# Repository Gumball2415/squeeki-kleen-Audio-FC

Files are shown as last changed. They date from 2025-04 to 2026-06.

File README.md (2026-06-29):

# squeeki-kleen! Audio FC

an open-source hardware external preamp modboard for the NES and FamiCom

## About

A few months ago, I discovered the main source of noisy interference for the audio in the FamiCom, which is the hex inverter chip. The other signals passing through the hex inverter chip is the interference heard in the audio.

Therefore, to reduce the interference as much as possible, the APU pins and preamp circuit must be completely isolated from the hex inverter chip. This is where this modboard comes in.

Note that this KiCad project is optimized for JLCPCB manufacturing, so you may have to modify how the gerber files are generated, remove the part number silkscreen on the back, etc.

<div align="center">
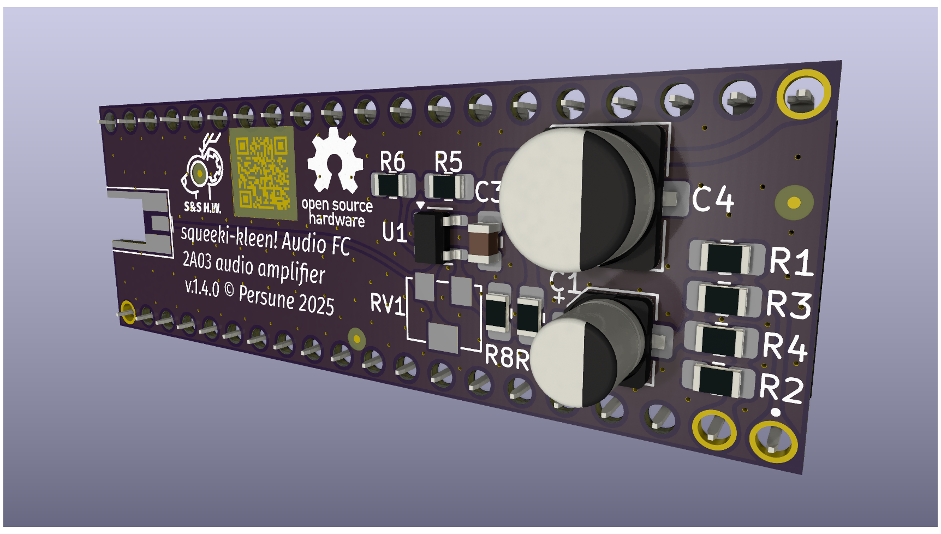
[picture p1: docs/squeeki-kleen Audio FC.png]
	
</div>

## Installation

This demonstration uses the RF FamiCom motherboard, revision CPU-07. However, these requirements can be easily adapted to different consoles and motherboard revisions, such as the NES.

This demonstration also uses an earlier revision board, so the look may differ, but the instructions should remain the same.

Here is the full motherboard overview of what modifications need to be done:

<div align="center">

</div>

### Instructions

1. Isolate Pin 1 and 2 of the 2A03 by cutting their traces as shown:

<div align="center">
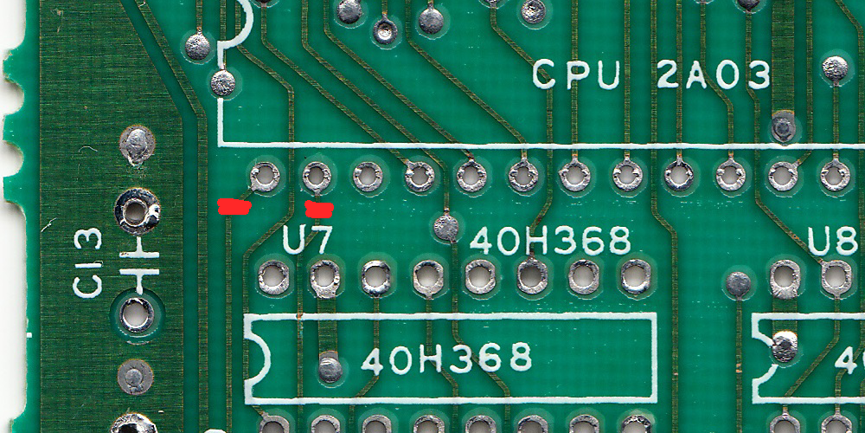
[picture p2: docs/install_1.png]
	
</div>

2. Short the input of the stock preamp circuit to ground (solder bridge violet, pins 14 and 15 of U7)

<div align="center">
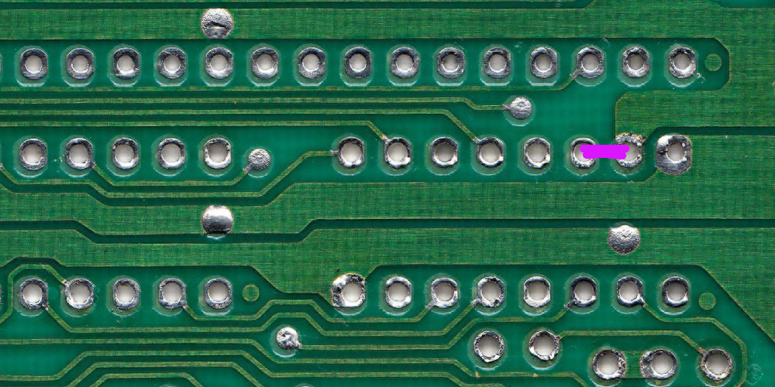
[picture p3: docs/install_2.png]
	
</div>

3. Isolate the output of the stock preamp circuit and the old audio path (cut blue)
	- Cut the trace after the `SOU` test pad
	- Cut the trace of R7 before it goes to pin 13 of U7
	- Isolate the via near C11, which leads to pin 45 of the cartridge slot. This prevents the leftover trace leaving the `SOU` test pad acting as an antenna to unwanted interference near the bus traces.

<div align="center">
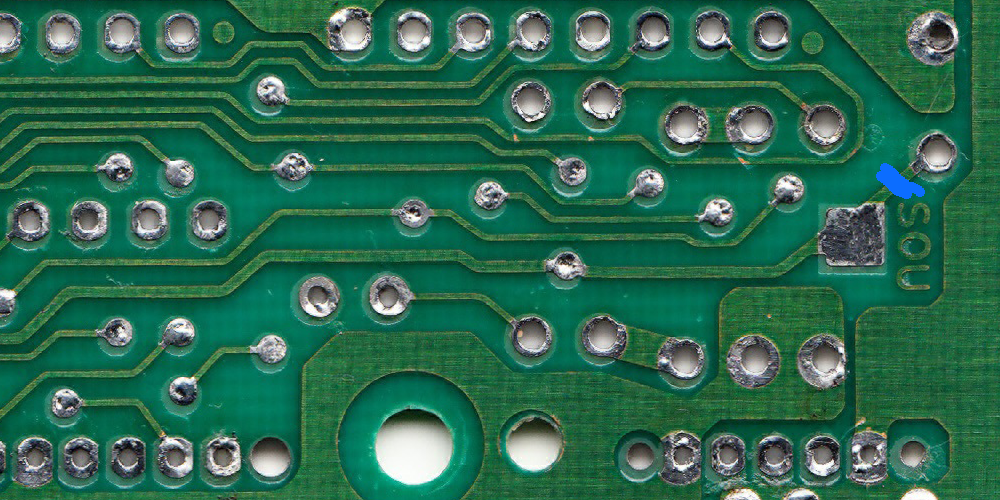
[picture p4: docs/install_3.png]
	
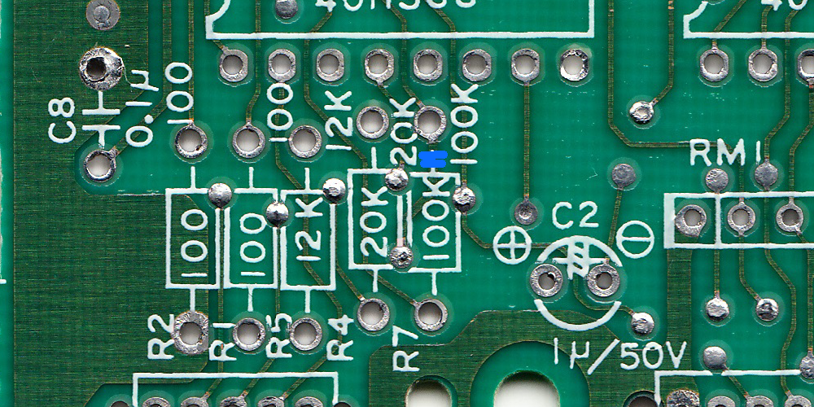
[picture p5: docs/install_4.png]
	
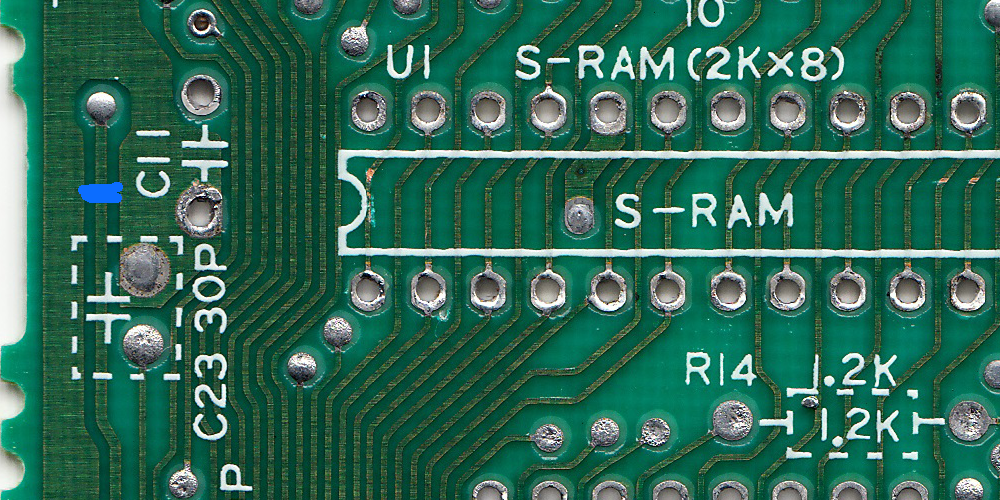
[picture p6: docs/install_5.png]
	
</div>

Once these are done, simply install the board underneath the 2A03, and connect the output pad to the appropriate output path.

### Connecting the output

When installed, it will look something similar to this:

<div align="center">

</div>

Note that this is a v0.9 prototype, where the output goes to the left. *The latest version's output goes to the right*.

Jump the output to pin 45 of the cartridge connector in order for the audio to be mixed with cartridge expansion audio as follows:

<div align="center">
	
</div>

## License

This is licensed under the [TAPR Open Hardware License](http://www.tapr.org/OHL).

Copyright Persune 2026.

## Credits

Special thanks to:

- The NESDev and MDFourier community for advice and help
- [@tianfeng33](https://github.com/tianfeng33) for help with the preamp circuit
- konakonaa for the squeeki-kleen! namesake
- [@Lockster-Inc](https://github.com/Lockster-Inc) for the FamiCom PCB scans

## Support

If you enjoy this project or find it helpful, please support me on [Ko-Fi](https://ko-fi.com/persune) or [Patreon](https://www.patreon.com/persune)!

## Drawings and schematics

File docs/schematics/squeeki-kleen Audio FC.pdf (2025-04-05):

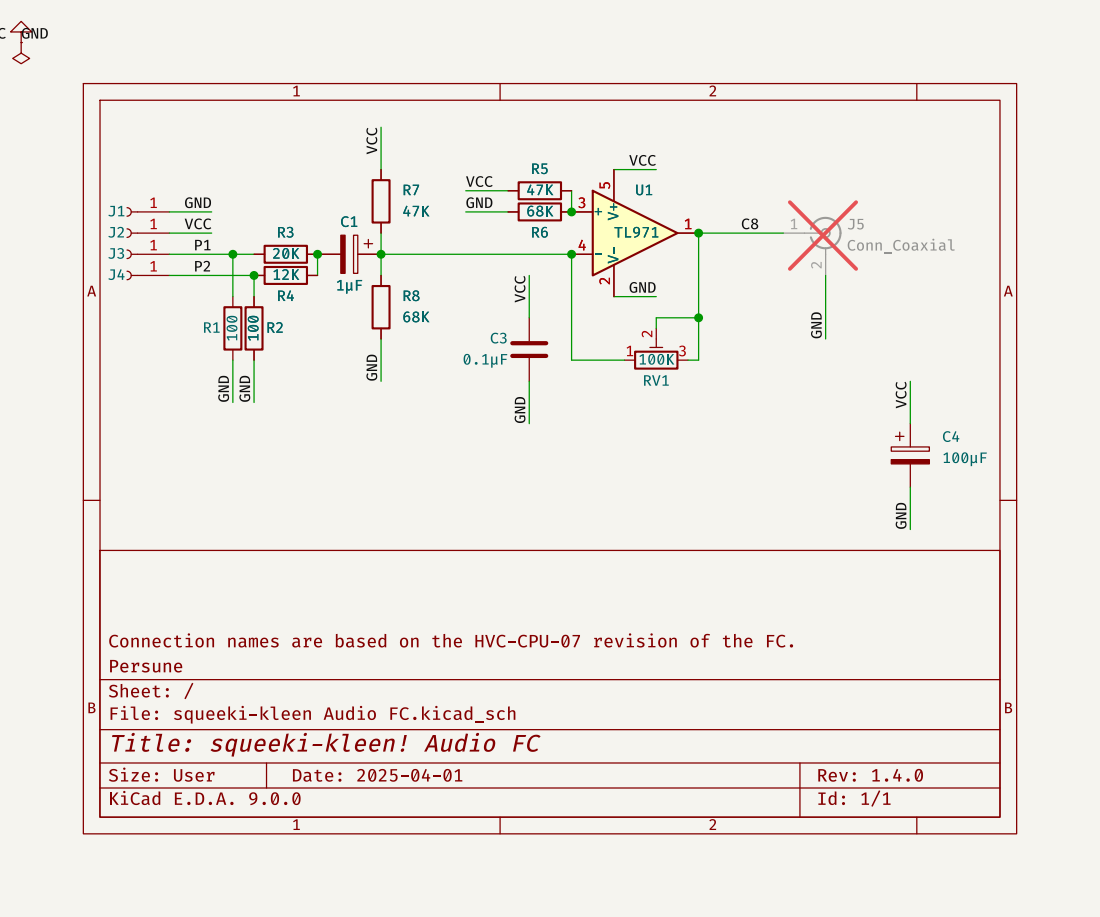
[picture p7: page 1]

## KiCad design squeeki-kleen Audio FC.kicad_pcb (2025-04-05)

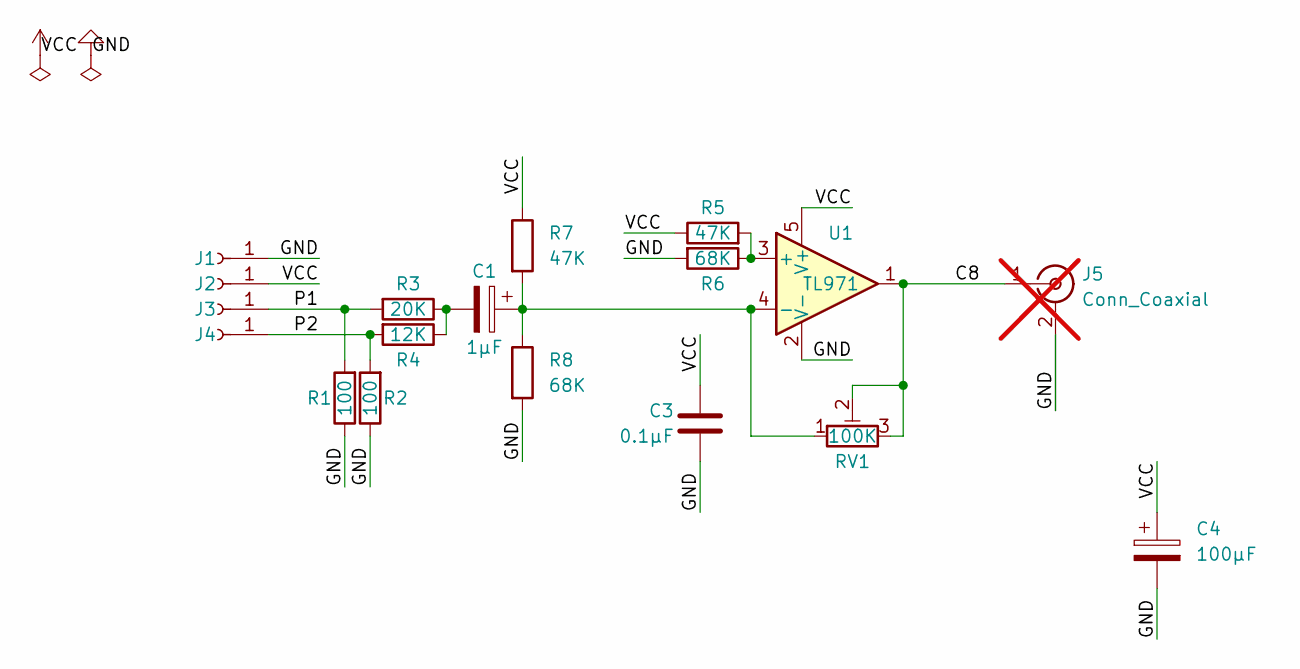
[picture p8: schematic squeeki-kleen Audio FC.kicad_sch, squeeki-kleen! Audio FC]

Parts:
C1: 1µF; CP_Elec_4x5.4
C3: 0.1µF; C_0805_2012Metric_Pad1.18x1.45mm_HandSolder
C4: 100µF; CP_Elec_6.3x4.5
J1: GND; Custom_THT
J2: VCC; Custom_THT
J3: P1; Custom_THT
J4: P2; Custom_THT
J5: Conn_Coaxial; MMCX_Molex_73415-0961_Horizontal_0.8mm-PCB; not fitted
R1, R2: 100; R_0805_2012Metric_Pad1.20x1.40mm_HandSolder
R3: 20K; R_0805_2012Metric_Pad1.20x1.40mm_HandSolder
R4: 12K; R_0805_2012Metric_Pad1.20x1.40mm_HandSolder; LCSC C316787
R5, R7: 47K; R_0805_2012Metric_Pad1.20x1.40mm_HandSolder
R6, R8: 68K; R_0805_2012Metric_Pad1.20x1.40mm_HandSolder
RV1: 100K; Potentiometer_Bourns_3224W_Vertical; LCSC C53229
U1: TL971; SOT-23-5

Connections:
/C8: J5.1 (In), RV1.2, RV1.3, U1.1
/P1: J3.1, R1.2, R3.2
/P2: J4.1, R2.2, R4.2
GND: C3.2, C4.2, J1.1, J5.2 (Ext), R1.1, R2.1, R6.2, R8.2, U1.2 (V-)
unnamed: C1.2, R3.1, R4.1
unnamed: R5.2, R6.1, U1.3 (+)
unnamed: C1.1, R7.2, R8.1, RV1.1, U1.4 (-)
VCC: C3.1, C4.1, J2.1, R5.1, R7.1, U1.5 (V+)

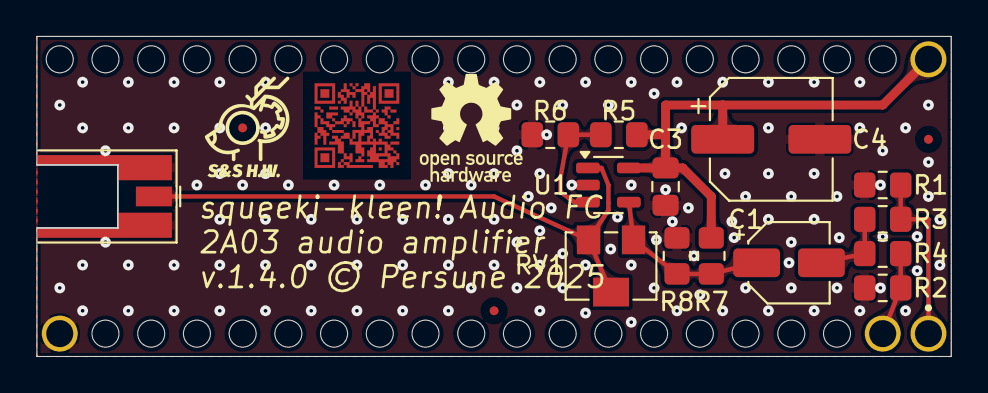
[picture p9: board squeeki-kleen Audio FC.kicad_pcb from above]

Board: 2 copper layers, 50.8 x 17.8 mm, 21 parts (0 on the bottom side), 8 nets.

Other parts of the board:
Ref**: Val**; qr
svg2mod: G***; oshw-logo 6x6mm
svg2mod#2: G***; maustech icon fiducial 0-50mm 1-50mm

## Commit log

2021-09-04 Add readme and license
    [squeeki-kleen Audio FC.kicad_pcb]
2021-10-21 Rev. 1.1.0
    - change edge cuts to be more panelization-friendly
    - use plated through holes instead of castellated holes
    - dagga art by https://twitter.com/pickleknotart
    - widen ground pad next to the audio out pad
    [squeeki-kleen Audio FC.kicad_pcb, squeeki-kleen Audio FC.sch]
2021-10-21 C3 capacitor filtering disclaimer
2021-10-23 Rev 1.2.0
    - change edge cuts to reduce unused space
    - add THT on pin 30 to add support
    - add labels on output pads
    - thanks to grievre for feedback
    [squeeki-kleen Audio FC.kicad_pcb]
2022-04-23 KiCad 6.0
    [squeeki-kleen Audio FC.kicad_pcb, squeeki-kleen Audio FC.kicad_sch]
2022-04-23 ignore KiCad 6 backups
2022-04-23 Curvify traces
    [squeeki-kleen Audio FC-rounded.kicad_pcb]
2022-04-23 Art by Pickleknot
    [squeeki-kleen Audio FC-rounded.kicad_pcb]
2022-12-13 Adjust via size and copper fill
    [squeeki-kleen Audio FC.kicad_pcb]
2022-12-13 Add teardrops, HTML BOM, and trace rounding
    [squeeki-kleen Audio FC-rounded.kicad_pcb, squeeki-kleen Audio FC.kicad_pcb]
2022-12-13 Update PCB image
2022-12-13 Update version
    [squeeki-kleen Audio FC-rounded.kicad_pcb, squeeki-kleen Audio FC.kicad_pcb, squeeki-kleen Audio FC.kicad_sch]
2025-04-05 Update board layout, add level adjustment
    [squeeki-kleen Audio FC-rounded.kicad_pcb, squeeki-kleen Audio FC.kicad_pcb, squeeki-kleen Audio FC.kicad_sch]
2025-04-05 Update schematics

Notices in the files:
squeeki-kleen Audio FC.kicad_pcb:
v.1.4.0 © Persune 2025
